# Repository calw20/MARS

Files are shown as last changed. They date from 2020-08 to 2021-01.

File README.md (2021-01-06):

# MARS Control Software

## Warning

> :warning: A good ~~30%~~, ~~50%~~, *large amount* of this documentation is out of date or just wrong..... It's being worked on..... - [Cal]

The code for the MARS payload.  
This Readme _should_ cover everything but if it dosn't then just yell at me... [_Cal_]

## Install

Once you have [cloned](#git) [or downloaded](https://github.com/calw20/MARS/archive/master.zip)  the repo, [setup](#setup) the Arduino making any changes needed and then run the [Upload](Upload.ps1) script. This will download the correct libraries, make sure that the correct header files are created and upload the code to the Arduino.
With some luck everything _should_ just work.

>:notebook_with_decorative_cover: If you try and open [main.ino](main.ino) then the Arduino IDE ~~will~~ _may_ throw a hissy-fit and not want to work with you. Try if you like but it may break....

## Usage

There are _two_ main ways to make the Arduino rotate the filter plate in the sandwich; the Button and _falling **past**_ an Altitude. By default both are enabled, and the specific altitudes that should trigger rotation are defined in [payload_settings.h](payload_settings.h)  under `FILTER_HEIGHTS`. Other settings such as the apogee height can also be found in that file. See [Calibration and Configuration](#Calibration-and-Configuration) for more information.

## Setup

### Calibration and Configuration

For ease of debugging and programming most variable and configuration options needed for deployment are in the [payload_settings.h](payload_settings.h) header file.

#### Operational Parameters

>:warning: Currently if you _enable_ `ROTATE_ON_ALTITUDE` then things **_will_** break.  
>:notebook_with_decorative_cover: Remember once changes have been made to any of the files, you need to _re-upload_ the code to the arduino.

| Option |  Possible Values  |Explanation|
|---|---|-|
|`APOGEE_HEIGHT` |Any `integer` |In meters, what height should be considered to be the highest point of flight.|
|`FILTER_HEIGHTS` |Array of `integers`|When descending, at what heights (meters) should the filter plate be rotated. For example if there were _two_ filters and _one_ quarantine blank and the first filter is needed to be rotated into place at 40m, the second is then moved into place at 30 then the quarantine blank is moved back into place at 10m above the ground, then the array would look like this: `{40, 30, 10}`|
|`ROTATE_ON_ALTITUDE`|`true` or `false`  |Should rotation events occur when descending.|
|`ROTATE_ON_BUTTON`  |`true` or `false`  |Should the button trigger a rotation event.|
|`STEPS_PER_ROTATION`|Any `integer` |How many _stepper motor steps_ will are need to move a filter in position a -> b|

### Wiring Layout

>:notebook_with_decorative_cover: The LED shown to be connected to pin 13 is not _technically_ needed due to it sharing the pin with the inbuilt LED...  
>:notebook_with_decorative_cover: While a MicoSD-Card breakout board is shown in the diagram, any SD compatible board will work. (We use an el-cheapo regular SD-Card breakout board).  
>:closed_book: The pin breakout on each board may differ but commonly `DO = MISO = 50` and `DI = MOSI = 51`

If needed the see the sub-components data sheet for information regarding setup or use.

* [Stepper Motor Controller](https://wiki.dfrobot.com/TB6600_Stepper_Motor_Driver_SKU__DRI0043)
* [BMP280 Pressure Sensor](https://learn.adafruit.com/adafruit-bmp280-barometric-pressure-plus-temperature-sensor-breakout/arduino-test)
* [MPU6050 6-Axis Accelerometer/Gyro ](https://www.dfrobot.com/product-880.html)
* [nRF24L01+ Transceiver](https://www.sparkfun.com/products/691)

>:orange_book: We may want to use [this](https://www.sparkfun.com/products/705) version of the transceiver as it has an RP-SMA 2.4GHz antenna connector on it

>:heavy_exclamation_mark: *Wiring Layout* is out of date. It does not show the MPU6050 or nRF24L01+

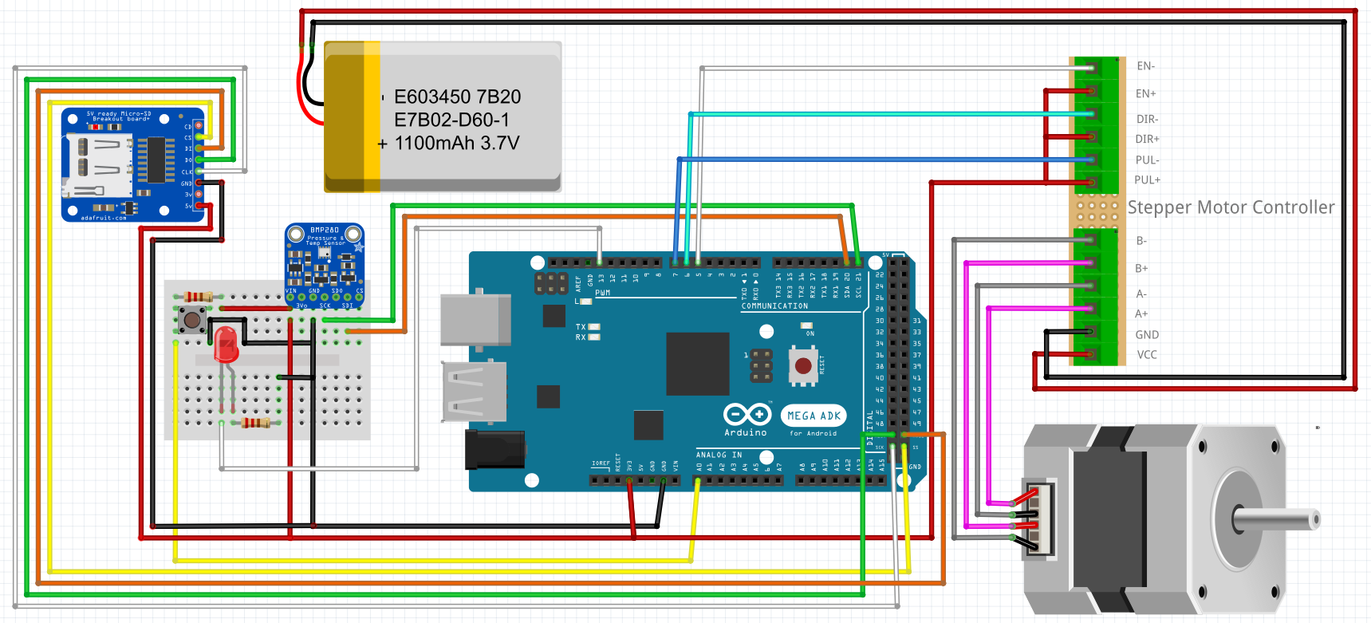
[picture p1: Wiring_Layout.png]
Wiring Layout


### Debugging

> See [Warning]

At compile time, the pre-build ~~python script~~ _"tool chain"_ will auto-magically* create a header file to add in a few useful things, **but** it will also _ENABLE_ the debug logging to the arduino's serial port. By default the serial port speed is `115200` and if you need to change it, then change the `SERIAL_BAUD` option in [main.ino](main.ino) to what ever speed you need.

#### Contributing to the codebase

See the [Contributing](CONTRIBUTING.md) file for info on how to setup the folder and make changes.
>:exclamation: Note: It is assumed you have read the [Git](#git) and [Install Commands](#Install-Commands) sections.

### Git

It is *__HIGHLY__* recommended you use git to clone the repo as code [upload script](Upload.ps1) was built to be able to auto-magically* download the latest version of the code. It would also allow for any changes in code made locally to be uploaded and synced, _potentially*_ making debugging _"easier"_. For more info on how to get git and use git check out the [Git Beginner Tutorial](https://product.hubspot.com/blog/git-and-github-tutorial-for-beginners) done by GitHub.  
<sub><sub>* Due to the fundamental love<->hate relationship we mortals have with the debugging gods, auto-magic systems may not be _cooperative_ at all times.</sub></sub>

#### Install Commands

>:warning: __Important Note:__ Because computers, when you try to launch the upload script it *may* yell at you about  *"Execution Policies"* or *"Unauthorized Access"* errors. This is normal, [TL;DR](https://docs.microsoft.com/en-us/powershell/module/microsoft.powershell.core/about/about_execution_policies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) its for security. If this does occur you need to open `powershell` as an administrator (search for it in the start-menu, then right click) and then run this `Set-ExecutionPolicy RemoteSigned`  command (or equivalent)  to allow scripts to be executed. Then you should be good to go!

```dos
git clone https://github.com/calw20/MARS-Prototype.git
cd MARS-Prototype
Upload.ps1
```

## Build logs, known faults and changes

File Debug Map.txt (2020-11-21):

+========================+
|       All Modules      |
+------------------------+
| Headers:          H    |
| No Headers:      -H    |
| Show Header Str: +H    |
+========================+
|      Root Module       |
+------------------------+
| Root Header:     NH    |
| SysTime Minutes: TM    |
| SysTime Seconds: T     |
+========================+
|   Accel\Gyro Module    |
+------------------------+
| Accel Data:  a         |
| Gyro Data:   g         |
+========================+
|    Fan Controllers     |
+------------------------+
| Fand Speed: I          |
+========================+
|    Pressure Sensor     |
+------------------------+
| Pressure Sensor All: B |
| PS Alt: A              |
| PS Prs: P              |
| PS Tmp: D              |
+========================+
|       GPS Module       |
+------------------------+
| All GPS Data: G        |
| Location:     L        |
| Time:         t        |
| Date:         d        |
| Satellites:   S        | 
+========================+

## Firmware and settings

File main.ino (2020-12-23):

//Include the right libs
#include "payload_settings.h" //This holds all the payload settings. I.E Rotaion Heights, Apogee Height, ect
#include "src/debug/debug.h"
#include "src/mars_root_module/data_types.h"
#include "src/mars_root_module/mars_root_module.h"
#include "src/pressure_sensor/pressure_senor.h"
#include "src/stepper_motor/stepper_motor.h"
#include "src/sd_card/sd_card.h"
#include "src/accell_gyro/accell_gyro.h"
#include "src/fan_controllers/fan_controllers.h"
#include "src/gps/gps.h"

#include "src/wireless_module/wireless_module.h"
#include "src/wireless_radio/wireless_datatypes.h"

#include <SdFat.h>

//^You really should only have to change these...
#define SERIAL_BAUD 115200
#define BUTTON_PIN A0

RootModule MARS_RootModule;
PressureSensor pressureSensor(MARS_RootModule);
SDCardAdapter sdCard(MARS_RootModule);
StepperMotor sandwitch(MARS_RootModule);
AccellGyro accellGyro(MARS_RootModule);
FanController fanController(MARS_RootModule);
GPSModule gpsRadio(MARS_RootModule);
WirelessModule radioModule(MARS_RootModule, &sandwitch);

//Define a constant array - this defined in ./payload_settings.h
const float apogeeHeight = APOGEE_HEIGHT;

//Simple Redirection
TriColourLED *cLED1;
TriColourLED *cLED2;
payloadData &pData = MARS_RootModule.data;

/*
void mainAirLoop(){
    //[TODO] Latching
    bool hitApogee = false;

     while(sandwitch.currentFilter < sandwitch.maxFilterNumber || true){ //! Forced to be always enabled
        //Get Alt/Pressure
        pressureSensor.updateAltPressure();
        if (pressureSensor.altitude != pressureSensor.lastAltitude){
            DBG_FPRINT_SVLN("Current Altitude: ", pressureSensor.altitude);
        }

        //Get Accell/Gyro Data
        accellGyro.getMotion();
        accellGyro.printDebug("AG");

        //Write data to SD Card
        sdCard.writeCSVData();
        
        //See if we have hit Apogee
        if (!hitApogee & pressureSensor.altitude > APOGEE_HEIGHT){ //* Apogee detection enabled.
            hitApogee = true;
            DBG_FPRINT_SVLN("Just hit Apogee at: ", pressureSensor.altitude);
            DBG_FPRINTLN("Engaging the sandwich!");
            
        }

        //Rotate on button press
        if (rotateOnButton && digitalRead(BUTTON_PIN) & false){ //!Disabled - Enabled in ./payload_settings.h
            DBG_FPRINTLN("Button has been pressed!");
            digitalWrite(LED_PIN, HIGH);
            NEXT_FILTER(); //Next Filter
            
            while(digitalRead(BUTTON_PIN));
            digitalWrite(LED_PIN, LOW);
            DBG_FPRINTLN("Button has been released!");
        }

        //^ I hope this works (´。＿。｀)
        //\ (╯°□°）╯︵ ┻━┻) - The drift is killing me
        //Rotate once we have passed the right Altitudes
        if(rotateOnAltitude && hitApogee){ //* Enable - Enabled in  ./payload_settings.h 
            if (altitude < filterHeights[currentFilter]){
                DBG_FPRINT_SV("Reached current filter height ", altitude);
                DBG_FPRINT_SVLN(", for filter number ", currentFilter);
                NEXT_FILTER(); //Next Filter
            }
        }
    }
    
}*/

void mainAirLoop(){
    cLED1->setColour(LEDColours::CYAN);
    while(sandwitch.isAbleToRotate()){
        MARS_RootModule.updatePayloadData(true); //Update paloadData struct
        sdCard.writeCSVData();
        //sdCard.printCSVData();
        
        //[TODO] Do wireless Logic on the pad ie alt change sml
        //if (abs(pData.altitude[0] - pData.altitude[1]) < 5) WirlessUpdate()

        //See if we have hit Apogee
        //Check if we have passed a pre-determined apogee height or if the altitude has decreased
        //No _Automatic_ Flight Logic is performed if apogee has not been passed
        if (!pData.hitApogee && (pData.altitude[0] > apogeeHeight | pData.altitude[0] < pData.altitude[1])){
            pData.hitApogee = true;
            DBG_FPRINT_SVLN("Just hit Apogee at: ", pData.altitude[0]);
            DBG_FPRINTLN("Engaging the sandwich!");
            cLED1->setColour(LEDColours::GREEN);
        }

        //Rotate on button press
        if (pData.rotateOnButton && digitalRead(BUTTON_PIN)){
            DBG_FPRINTLN("Button has been pressed!");
            cLED2->setColour(LEDColours::MAGENTA);
            sandwitch.nextFilter();

            while(digitalRead(BUTTON_PIN));
            cLED2->setColour(LEDColours::BLACK);
            DBG_FPRINTLN("Button has been released!");
        }

        //Rotate once we have passed the right Altitudes
        if(pData.rotateOnAltitude && pData.hitApogee && sandwitch.shouldRotate()){ //* Enable - Enabled in  ./payload_settings.h 
            DBG_FPRINT_SV("Reached current filter height ", pData.altitude[0]);
            DBG_FPRINT_SVLN(", for filter number ", pData.currentFilter);
            sandwitch.nextFilter();
        }

        //^ I hope this works (´。＿。｀)
        //If the sandwitch is engaged run the fans
        if(pData.currentFilter > 0 && pData.currentFilter < pData.maxFilterNumber && fanController.getSpeed() != FAN_SPEED_LIMIT)
            fanController.setSpeed(FAN_SPEED_LIMIT);
        else
            fanController.setSpeed(0);

        fanController.writeSpeed();
    }
    cLED1->setColour(LEDColours::WHITE);
    fanController.setSpeed(0);
    DBG_FPRINTLN("All samples collected!");
    DBG_FPRINTLN("Please reset the Mega.");
    MARS_RootModule.updatePayloadData(true);
    sdCard.writeCSVData();
    sdCard.closeFile();

    //[TODO] Wireless Data
    //while(true) {}
}

void setup(){
    //Serial Setup
    #if DO_DEBUG
        Serial.begin(SERIAL_BAUD);
        DBG_FPRINTFN("Build Date: ", "%s", BUILD_DATE);
        DBG_FPRINTFN("Build Version: ", "%s", BUILD_VERSION);
    #endif


    //Build and Initialize all the modules
    DBG_FPRINTLN("Begining Initialization....");
    MARS_RootModule.init();
    

    //[TODO] Move this to SDCard Module?
    //Write all the consts to a file
    char constFileName[14] = "constFile.csv";
    File constFile = sdCard.openFile(constFileName);
    constFile.println("UTC Date,Altitude Offset,Sea Level Pressure");
    char __constFileBuff__[128];
    sprintf(__constFileBuff__, "%lu,%lu,%f", 
        (unsigned long)gpsRadio.getDate(), (unsigned long)pData.altGndLvlOffset, pressureSensor.getSeaLevelPressure()
    );
    constFile.println(__constFileBuff__);
    constFile.flush();
    constFile.close();

    sdCard.initFlightDataFile();
    cLED1 = MARS_RootModule.cLED1;
    cLED2 = MARS_RootModule.cLED2;

    //Blink the light ~5? times
    for(int i = 0; i <= 12 ; i++){
        cLED1->setColour(((i%2 == 1) ? LEDColours::GREEN : LEDColours::BLACK));
        if (DO_INIT_DELAY) delay(200); //This slows things down..... *wow* :/
    }

    DBG_FPRINTLN("System is setup and configured!");

    //Hang until armed
    //[TODO] Enable this ¯\_(ツ)_/¯
    DBG_FPRINTLN("System not armed, wating for signal!");
    unsigned long beginArmWait = millis();
    unsigned long cLoop = beginArmWait;
    while(!MARS_RootModule.systemArmed){
        //Flash the light
        if (millis()-cLoop > 500) cLoop = millis();
        cLED2->setColour((millis()-cLoop > 500) ? LEDColours::CYAN : LEDColours::BLACK);

        //Check if there has been a button press
        if (digitalRead(BUTTON_PIN)){
            DBG_PRINTLN("Button Press Detected!");
            cLED2->setColour(LEDColours::YELLOW);
            while(digitalRead(BUTTON_PIN)){} //Wait for button release
            DBG_PRINTLN("Button Release Detected! Armming from button press");
            cLED2->setColour(LEDColours::BLACK);
            MARS_RootModule.systemArmed = true;
        }

        //Wireless Command Handling
        radioModule.waitForHandledCommand();

        //Arming Timeout
        if (ARMING_TIMEOUT > 0 && millis()-beginArmWait > ARMING_TIMEOUT){
            DBG_PRINTLN("Arming order timed out. System will arm based on this.");
            MARS_RootModule.systemArmed = true;
        }
    }

    DBG_FPRINTLN("System armed. Begining Flight Loop!");
    
    mainAirLoop();
}

//NOP
void loop(){}

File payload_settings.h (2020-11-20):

//Payload Settings
//This _should_ be all you need to edit for proper operation

#define ALT_SAMPLE_COUNT 6     //Number of samples to use when calibrating the Altitude sensor
#define STEPS_PER_ROTATION 1600 //How many steps to go from filter plate a -> b
#define APOGEE_HEIGHT 580      //When is Apogee? (m) - We may need to offset this due to drift 30000ft / 3.281 = 9144m
//[TODO] Remove this?
#define ROTATE_ON_ALTITUDE true        //Should the filter plate rotate at the altitudes below?
#define ROTATE_ON_BUTTON   true        //Should the filter plate rotate on button presses?
#define FILTER_HEIGHTS {500, 400, 300, 200, 100} //When does the sandwich need to turn (m)

#define FAN_SPEED_LIMIT 25

//Timeouts
//NOTE: If these are 0 then there will be no timeout condition
#define RADIO_TIMEOUT 5*100 //[milli]Seconds
#define ARMING_TIMEOUT 30*100 //[milli]Seconds

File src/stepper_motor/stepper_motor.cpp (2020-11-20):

#include "stepper_motor.h"

//Makes things look neater I guess?
bool StepperMotor::init(){
    pinMode(STEP_PULSE_PIN, OUTPUT); //StepMC Pulse Pin
    pinMode(STEP_DIREC_PIN, OUTPUT); //StepMC Direction Pin
    pinMode(STEP_ENABL_PIN, OUTPUT); //StepMC Enable Pin

    //First thing we need to do is lock the steper motor, last thing we want
    //is the sandwich rotateing.... (•‿•)
    digitalWrite(STEP_ENABL_PIN, HIGH);
    maxFilterNumber = sizeof(filterHeights)/sizeof(*filterHeights);
    marsRoot->data.maxFilterNumber = maxFilterNumber;
    return true;
}

void StepperMotor::genericError(const char* func, const char* file, u16 failLine){
    DBG_FPRINTLN("##################### Sandwitch Error Info #####################");
    DBG_FPRINTF("The Pressure Sensor has experienced an Error of type: ","[%s]\r\nMore Details;\r\n",
        CrashTypeText[status]); //DBG_PRINTLN();
    printErrorInfo(func, file, failLine);
    printDebug("-H");
    DBG_PRINTLN();
}

void StepperMotor::printDebug(String printValues){
    //^ Defined in debug.h? //#define CHK_LETTER(letter) printValues.indexOf(letter) > -1
    if (CHK_LETTER("-H")) printValues = "Z";

    if (CHK_LETTER("H")) DBG_FPRINTLN("======================== Sandwitch Info ========================");
    
    if (CHK_LETTER("Z")){
        DBG_FPRINT_SVLN("Sandwitch currently at sample: ", currentFilter);
        DBG_FPRINT_SVLN("Maximum number of samples: ", maxFilterNumber);
        DBG_FPRINT("Micro Step Delay currently: "); DBG_PRINT(MICRO_STEP_DELAY); DBG_FPRINTLN(" ms");
    }
}

u8 StepperMotor::getCurrentFilter(){
    return currentFilter;
}

//Rotate the sandwich a number of steps
//[TODO] 19-11: This need in person testing as I have disabled fliping the step direction
//\ here and also the negative in STEPS_PER_ROTATION /payload_settings.h ¯\_(ツ)_/¯
void StepperMotor::rotateSandwitch(long int steps){
    //Need to flip steps so that it goes the right direction
    //steps *= -1;

    long int absSteps = abs(steps); //Argh this is a macro and for "speed" reasons Ill do this 
        //it could be more memory efficient to use the macro everywhere but meh, its a mega
    
    //[TODO] Check this works...
    DBG_FPRINTFN("Sandwitch needs to move ", "%li steps %s.", 
        absSteps, (steps/absSteps + 1) ? "Forward" : "Backwards");
    
    digitalWrite(STEP_DIREC_PIN, (steps/absSteps + 1)); //If steps is negative then rotate backwards.
    //Send the steps
    for (int i=0; i <= absSteps; i++){
        digitalWrite(STEP_PULSE_PIN, HIGH);  //Set pulse high
        delayMicroseconds(MICRO_STEP_DELAY); //Wait
        //delay(30);
        digitalWrite(STEP_PULSE_PIN, LOW);   //Set pulse low
        delayMicroseconds(MICRO_STEP_DELAY); //Wait
        //delay(30);
    }
}

bool StepperMotor::nextFilter(){
    if (isAbleToRotate()) {
        DBG_FPRINT_SVLN("Currently on filter: ", currentFilter);
        currentFilter++;
        
        //Only change the LED colour if a filter change is requested
        //nextFilter is more of a MARS func then rotate
        LEDColours currentColour = marsRoot->cLED1->getColour();
        marsRoot->cLED1->setColour(LEDColours::YELLOW);
        rotateSandwitch(STEPS_PER_ROTATION);
        marsRoot->cLED1->setColour(currentColour);

        DBG_FPRINT_SVLN("Now on filter: ", currentFilter);
        return true;
    } else {
        DBG_FPRINTLN("Request to rotate, however already completed one full turn!");
        return false;
    }
}

bool StepperMotor::isAbleToRotate(){
    return currentFilter < maxFilterNumber;
}

bool StepperMotor::shouldRotate(){
    if (currentFilter < maxFilterNumber){
        return  marsRoot->data.altitude[0] < filterHeights[currentFilter];
    } else {
        return false;
    }
}

bool StepperMotor::updatePayloadData(bool forceDataUpdate){
    marsRoot->data.currentFilter = getCurrentFilter();
    return true;
}

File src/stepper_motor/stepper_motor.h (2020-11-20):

#ifndef __MARS_STEPPER_MOTOR_H__
#define __MARS_STEPPER_MOTOR_H__

#include "Arduino.h"
#include "../debug/debug.h"
#include "../../payload_settings.h"
#include "../mars_root_module/data_types.h"
#include "../mars_root_module/mars_root_module.h"

#define LED_PIN LED_BUILTIN     //Diagnostic LED Pin
#define STEP_PULSE_PIN 7        //Stepper Motor Controller Pulse Pin (pwm)
#define STEP_DIREC_PIN 6        //Stepper Motor Controller Direction Pin
#define STEP_ENABL_PIN 5        //Stepper Motor Controller Enable Pin

#define MICRO_STEP_DELAY 50

const int filterHeights[] = FILTER_HEIGHTS;

class StepperMotor : public MARSCrashableModule {
    public:
        StepperMotor(RootModule &uncrashableParent, bool addSelfToParent = true) 
            : MARSCrashableModule(uncrashableParent, addSelfToParent) {};
        bool init() override;
        void printDebug(String = "Z") override;
        void genericError(const char* func, const char* file, u16 failLine) override;
        bool updatePayloadData(bool forceDataUpdate) override;
        
    public:
        void rotateSandwitch(long int steps);
        //void nextFilter(u8& currentFilter);
        bool nextFilter();
        u8 getCurrentFilter();
        bool isAbleToRotate();
        bool shouldRotate();

    private:
        u8 currentFilter = 0;
        u8 maxFilterNumber = 0;
        
};

#endif

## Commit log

2020-08-20 First Push
    [Wiring_Layout.fzz]
2020-08-20 Add fan controller logic
2020-08-20 Impliment Fan Controll
2020-09-12 Update fan control
2020-09-26 Added Colour LED's
2020-10-13 Add LED Bootstrap
2020-11-19 Update ledDriver Lib
2020-11-19 Update main flight loop & LED status keys
2020-11-19 Make StepperMotor::shouldRotate() rely on payloadData
2020-11-19 Update stepper motor logic
2020-11-19 Fix Pressure Sensor Module
2020-11-20 Fix Syntax *More* Errors
    [main.ino, stepper_motor.cpp]
2020-11-20 Impliment framework for selectAlt in pData
2020-11-20 Enable Calibration factors for accell_gyro
2020-11-20 Enable accell/gyro calibration & fix syntax
    [fan_controllers.cpp, mars_root_module.h]
2020-11-22 Inital Wireless Radio Work
2020-11-22 Refector switches out into individual functions
2020-11-29 Disable the wireless MODULE
2020-11-29 Refactor Wireless Radio
2020-11-29 Begin MARS wireless handling
2020-12-01 Impliment WirelessRadio::maxDataBufferSize()
2020-12-01 Disable the proper way of computing WirelessRadio::maxDataBufferSize()
2020-12-01 Impliment timout = 0 to be infinate wait in WirelessRadio
2020-12-01 Add stepper to wirelessRadio
2020-12-23 Impliment Wireless Communication
